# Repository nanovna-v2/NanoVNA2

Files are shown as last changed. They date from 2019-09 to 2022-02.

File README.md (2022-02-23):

# NanoVNA V2 (S-A-A-2)
This repository contains the NanoVNA V2 schematics and PCB layout designs.

Copyright (C) OwOTech 2020 <edelswartz123@gmail.com>, all rights reserved.

The design is licensed under CC-BY-NC-SA (see LICENSE file).

## V2_2 (V2.2) design files
- [v2_2.sch](v2_2.sch) (gEDA gschem schematic)
- [v2_2.pcb](v2_2.pcb) (gEDA PCB)
- [Schematic (png)](v2_2.png)
- [Schematic (pdf)](v2_2.pdf)

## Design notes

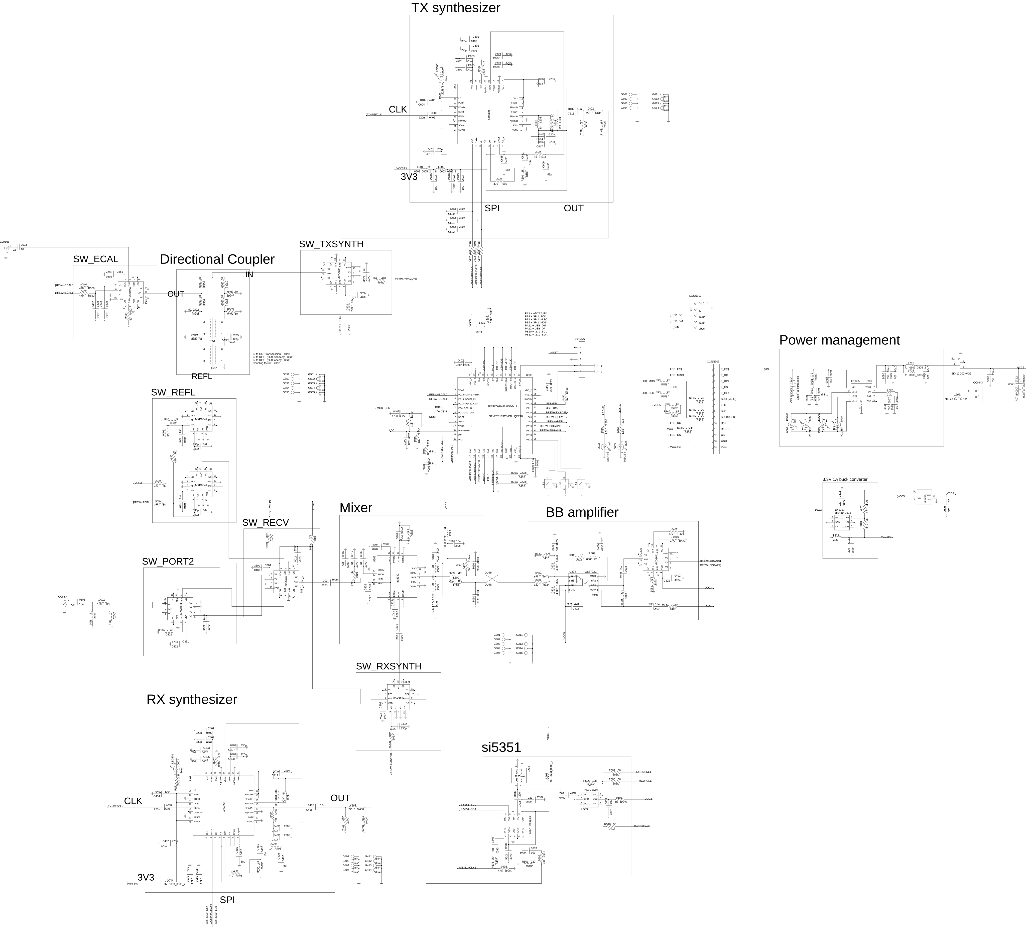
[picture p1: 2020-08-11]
v2_2.png

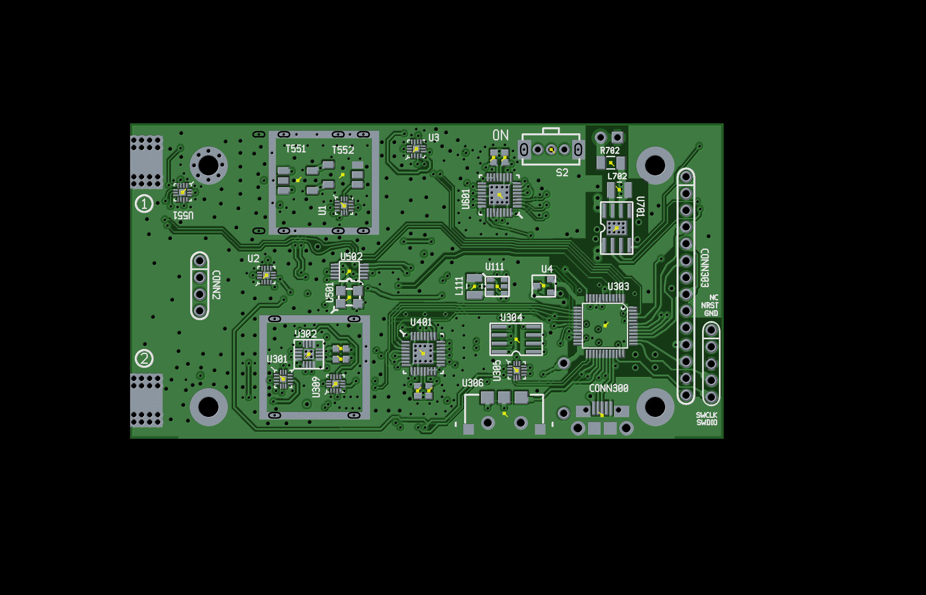
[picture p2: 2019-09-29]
fab/v2_0-20190929_12_02/v2_0-20190929_12_02-smt-top.png

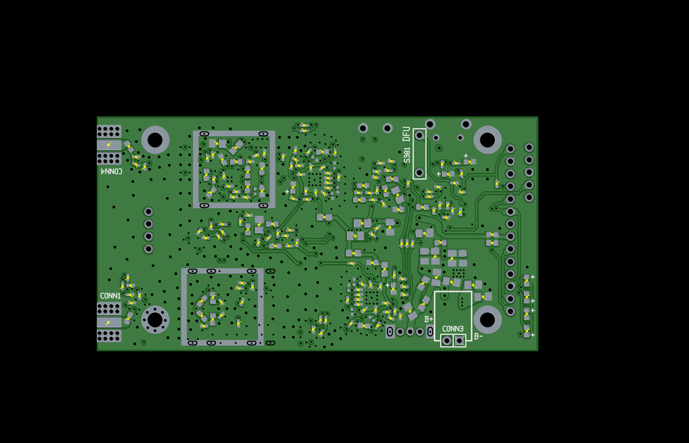
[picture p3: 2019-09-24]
fab/v2_0-20190924_08_28/v2_0-20190924_08_28-smt-bottom.png

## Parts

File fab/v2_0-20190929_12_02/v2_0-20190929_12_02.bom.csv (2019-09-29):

refdes | dni | device | footprint | value
G502 | unknown | terminal | shield_15.6_14.6 | unknown
R559 | unknown | RESISTOR | 0402 | 50
R558 | unknown | RESISTOR | 0402 | 50
R555 | unknown | RESISTOR | 0402 | 50
R553 | unknown | RESISTOR | 0402 | 50
R556 | unknown | RESISTOR | 0603 | 68
R554 | unknown | RESISTOR | 0603 | 68
R552 | unknown | RESISTOR | 0603 | 68
R551 | unknown | RESISTOR | 0603 | 68
R702 | unknown | PTC 2A | 1206 | unknown
R505 | unknown | RESISTOR | 0402 | 120
R504 | unknown | RESISTOR | 0402 | 50
R312 | unknown | RESISTOR | 0402 | 120
C9 | unknown | CAPACITOR | 0805 | 22u
R311 | unknown | RESISTOR | 0603 | 10
CONN5 | unknown | CONNECTOR_5 | connector5 | unknown
C710 | unknown | CAPACITOR | 0805 | 10u
S2 | unknown | SK-12D02-VG3 | SK-12D02-VG3 | unknown
R12 | unknown | RESISTOR | 0402 | 50
R609 | unknown | RESISTOR | 0402 | 470
R608 | unknown | RESISTOR | 0402 | 470
R607 | unknown | RESISTOR | 0402 | 470
C622 | unknown | CAPACITOR | 0402 | 330p
C621 | unknown | CAPACITOR | 0402 | 330p
C620 | unknown | CAPACITOR | 0402 | 330p
C616 | unknown | CAPACITOR | 0402 | 470n
C613 | unknown | CAPACITOR | 0603 | 10u
C8 | unknown | CAPACITOR | 0603 | 10u
CONN4 | unknown | BNC | custom_sma4 | unknown
R9 | unknown | RESISTOR | 0402 | 120
R11 | unknown | RESISTOR | 0402 | 75
R10 | unknown | RESISTOR | 0402 | 75
R563 | unknown | RESISTOR | 0402 | 50
C553 | unknown | CAPACITOR | 0402 | 330p
R562 | unknown | RESISTOR | 0402 | 470
C552 | unknown | CAPACITOR | 0402 | 330p
R560 | unknown | RESISTOR | 0402 | 470
C551 | unknown | CAPACITOR | 0402 | 470n
U551 | unknown | MXD8641 | mxd8641 | unknown
R503 | unknown | RESISTOR | 0603 | 2.2
C329 | unknown | CAPACITOR | 0402 | 470n
R310 | unknown | RESISTOR | 0402 | 2.2k
R309 | unknown | RESISTOR | 0402 | 2.2k
C416 | unknown | CAPACITOR | 0402 | 470n
C413 | unknown | CAPACITOR | 0603 | 10u
R308 | unknown | RESISTOR | 0402 | 470
C323 | unknown | CAPACITOR | 0402 | 330p
U306 | unknown | K1-1502SA-01 | K1-1502SA-01 | unknown
R307 | unknown | RESISTOR | 0402 | 2.2k
S301 | unknown | dipswitch-2 | dip2 | unknown
LED302 | unknown | LED | 0603 | red
R306 | unknown | RESISTOR | 0402 | 1.5k
R8 | unknown | RESISTOR | 0402 | 75
R7 | unknown | RESISTOR | 0402 | 220
U4 | unknown | xc6206-3.0 | SOT23 | unknown
L601 | unknown | INDUCTOR | 0603_0805_2 | fb
C619 | unknown | CAPACITOR | 0603 | 10u
L602 | unknown | INDUCTOR | 0603_0805_2 | fb
L401 | unknown | INDUCTOR | 0603_0805_2 | fb
C111 | unknown | CAPACITOR | 0805 | 22u
R111 | unknown | RESISTOR | 0402 | 2.2k
R112 | unknown | RESISTOR | 0402 | 10k
C112 | unknown | CAPACITOR | 0805 | 22u
L111 | unknown | INDUCTOR | 1008 | 2.2u
U111 | unknown | JW5211 | SOT26 | unknown
CONN3 | unknown | xh2.54-angled | CONNECTOR 1 2 | unknown
LED704 | unknown | LED | 0603 | red
LED703 | unknown | LED | 0603 | red
LED702 | unknown | LED | 0603 | red
LED701 | unknown | LED | 0603 | red
C709 | unknown | CAPACITOR | 0805 | 10u
L703 | unknown | INDUCTOR | 0603_0805_2 | fb
L701 | unknown | INDUCTOR | 0603_0805_2 | fb
C706 | unknown | CAPACITOR | 0805 | 10u
C705 | unknown | CAPACITOR | 0805 | 10u
R701 | unknown | RESISTOR | 0603 | 2.2
C703 | 1 | CAPACITOR | 0805 | 22u
C701 | unknown | CAPACITOR | 0805 | 22u
C704 | 1 | CAPACITOR | 0805 | 10u
C702 | unknown | CAPACITOR | 0805 | 10u
C708 | unknown | CAPACITOR | 0805 | 10u
C707 | unknown | CAPACITOR | 0805 | 10u
L702 | unknown | INDUCTOR | 1008 | 2.2u
U701 | unknown | IP5305 | SO8_EP | unknown
CONN2 | unknown | CONNECTOR_4 | connector4 | unknown
R305 | unknown | RESISTOR | 0402 | 470
R303 | unknown | RESISTOR | 0402 | 120
R304 | unknown | RESISTOR | 0402 | 1.5k
C321 | unknown | CAPACITOR | 0603 | 10u
C322 | unknown | CAPACITOR | 0402 | 470n
U305 | unknown | MXD8641 | mxd8641 | unknown
C618 | unknown | CAPACITOR | 0402 | 1n
R605 | unknown | RESISTOR | 0402 | 120
C609 | unknown | CAPACITOR | 0402 | 1n
R603 | unknown | RESISTOR | 0402 | 470
R604 | unknown | RESISTOR | 0402 | 470
C611 | unknown | CAPACITOR | 0402 | 470n
C615 | unknown | CAPACITOR | 0402 | 10n
C617 | unknown | CAPACITOR | 0402 | 220n
R606 | unknown | RESISTOR | 0402 | 50
C610 | unknown | CAPACITOR | 0402 | 470n
C604 | unknown | CAPACITOR | 0402 | 470n
C606 | unknown | CAPACITOR | 0402 | 220n
LED601 | unknown | LED | 0603 | blue
R601 | unknown | RESISTOR | 0402 | 2.2k
C614 | 1 | CAPACITOR | 0402 | 220n
C612 | unknown | CAPACITOR | 0402 | 220n
L604 | unknown | INDUCTOR | 0603 | rffb
L603 | unknown | INDUCTOR | 0603 | rffb
R602 | unknown | RESISTOR | 0402 | 4.7k
C605 | 1 | CAPACITOR | 0402 | 330p
C603 | unknown | CAPACITOR | 0402 | 220n
C602 | 1 | CAPACITOR | 0402 | 330p
C601 | unknown | CAPACITOR | 0402 | 220n
C607 | 1 | CAPACITOR | 0402 | 330p
C608 | unknown | CAPACITOR | 0402 | 220n
U601 | unknown | adf4350 | custom_qfn32 | unknown
R6 | unknown | RESISTOR | 0402 | 470
R5 | unknown | RESISTOR | 0402 | 220
C6 | unknown | CAPACITOR | 0402 | 330p
C7 | unknown | CAPACITOR | 0402 | 470n
U3 | unknown | MXD8641 | mxd8641 | unknown
G501 | unknown | terminal | shield_15.6_14.6 | unknown
R4 | unknown | RESISTOR | 0402 | 470
R3 | unknown | RESISTOR | 0402 | 220
C5 | unknown | CAPACITOR | 0402 | 330p
C4 | unknown | CAPACITOR | 0402 | 470n
U2 | unknown | MXD8641 | mxd8641 | unknown
R2 | unknown | RESISTOR | 0402 | 470
R1 | unknown | RESISTOR | 0402 | 220
C3 | unknown | CAPACITOR | 0402 | 330p
C2 | unknown | CAPACITOR | 0402 | 470n
R302 | unknown | RESISTOR | 0402 | 220
R301 | unknown | RESISTOR | 0402 | 470
C304 | unknown | CAPACITOR | 0402 | 330p
C305 | unknown | CAPACITOR | 0402 | 470n
L303 | unknown | INDUCTOR | 0603_0805_2 | fb
C303 | unknown | CAPACITOR | 0805 | 10u
U1 | unknown | MXD8641 | mxd8641 | unknown
U301 | unknown | MXD8641 | mxd8641 | unknown
C1 | unknown | CAPACITOR | 0603 | 10u
CONN1 | unknown | BNC | custom_sma4 | unknown
T552 | unknown | 617DB-1023=P3 | cx2156nl | unknown
R557 | unknown | RESISTOR | 0402 | 50
T551 | unknown | 617DB-1023=P3 | cx2156nl | unknown
G302 | unknown | terminal | shield_15.6_14.6 | unknown
G301 | unknown | terminal | shield_15.6_14.6 | unknown
C302 | unknown | CAPACITOR | 0402 | 470n
R501 | unknown | RESISTOR | 0402 | 220
R502 | unknown | RESISTOR | 0402 | 120
C505 | unknown | CAPACITOR | 0603 | 10u
C504 | unknown | CAPACITOR | 0402 | 470n
C418 | unknown | CAPACITOR | 0402 | 1n
C301 | unknown | CAPACITOR | 0603 | 10u
U309 | unknown | MXD8641 | mxd8641 | unknown
C502 | unknown | CAPACITOR | 0805 | 22u
C501 | unknown | CAPACITOR | 0402 | 220n
U501 | unknown | YSO680PR | tcxo3225 | unknown
C503 | unknown | CAPACITOR | 0603 | 10u
U502 | unknown | si5351a | MSOP10 | unknown
R405 | unknown | RESISTOR | 0402 | 120
C409 | unknown | CAPACITOR | 0402 | 1n
R403 | unknown | RESISTOR | 0402 | 470
R404 | unknown | RESISTOR | 0402 | 470
C411 | unknown | CAPACITOR | 0402 | 470n
C415 | unknown | CAPACITOR | 0402 | 10n
C417 | unknown | CAPACITOR | 0402 | 220n
R406 | unknown | RESISTOR | 0402 | 50
C410 | unknown | CAPACITOR | 0402 | 470n
C404 | unknown | CAPACITOR | 0402 | 470n
C406 | unknown | CAPACITOR | 0402 | 220n
LED401 | unknown | LED | 0603 | blue
R401 | unknown | RESISTOR | 0402 | 2.2k
C414 | 1 | CAPACITOR | 0402 | 220n
C412 | unknown | CAPACITOR | 0402 | 220n
L404 | unknown | INDUCTOR | 0603 | rffb
L403 | unknown | INDUCTOR | 0603 | rffb
R402 | unknown | RESISTOR | 0402 | 4.7k
C405 | 1 | CAPACITOR | 0402 | 330p
C403 | unknown | CAPACITOR | 0402 | 220n
C402 | 1 | CAPACITOR | 0402 | 330p
C401 | unknown | CAPACITOR | 0402 | 220n
C407 | 1 | CAPACITOR | 0402 | 330p
C408 | unknown | CAPACITOR | 0402 | 220n
U401 | unknown | adf4350 | custom_qfn32 | unknown
R340 | unknown | RESISTOR | 0603 | 68
R339 | unknown | RESISTOR | 0603 | 68
R341 | unknown | RESISTOR | 0402 | 10k
CONN303 | unknown | LCD-ILI9341-2.4in | connector14 | unknown
C337 | unknown | CAPACITOR | 0402 | 1n
R338 | unknown | RESISTOR | 0402 | 1.5k
LED301 | unknown | LED | 0603 | blue
R335 | unknown | RESISTOR | 0402 | 1.5k
CONN300 | unknown | CONNECTOR_5 | custom_microusb2 | unknown
C328 | unknown | CAPACITOR | 0402 | 470n
C327 | unknown | CAPACITOR | 0402 | 470n
C326 | unknown | CAPACITOR | 0402 | 470n
C324 | unknown | CAPACITOR | 0402 | 10n
R331 | unknown | RESISTOR | 0402 | 220
C325 | unknown | CAPACITOR | 0603 | 10u
R330 | unknown | RESISTOR | 0402 | 10k
R329 | unknown | RESISTOR | 0402 | 10k
C320 | unknown | CAPACITOR | 0402 | 470n
R323 | unknown | RESISTOR | 0402 | 4.7k
R322 | unknown | RESISTOR | 0402 | 4.7k
R321 | 1 | RESISTOR | 0402 | 50
C317 | unknown | CAPACITOR | 0603 | 10u
C315 | unknown | CAPACITOR | 0603 | 10u
R325 | unknown | RESISTOR | 0402 | 4.7k
R324 | unknown | RESISTOR | 0402 | 120
L302 | unknown | INDUCTOR | 0805 | 22u
C318 | unknown | CAPACITOR | 0603 | 220n
R328 | unknown | RESISTOR | 0402 | 2.2k
U304 | unknown | GS8052 | SO8 | unknown
C316 | unknown | CAPACITOR | 0603 | 220n
C312 | unknown | CAPACITOR | 0603 | 220n
L301 | unknown | INDUCTOR | 0603 | rffb
L300 | unknown | INDUCTOR | 0603 | rffb
C314 | unknown | CAPACITOR | 0402 | 470n
C311 | unknown | CAPACITOR | 0402 | 470n
R319 | unknown | RESISTOR | 0603 | 10
R317 | unknown | RESISTOR | 0603 | 10
C307 | unknown | CAPACITOR | 0603 | 10u
R314 | unknown | RESISTOR | 0402 | 75
C309 | unknown | CAPACITOR | 0402 | 470n
C310 | unknown | CAPACITOR | 0402 | 470n
C313 | unknown | CAPACITOR | 0603 | 10u
R315 | unknown | RESISTOR | 0402 | 2.2k
C308 | unknown | CAPACITOR | 0402 | 330p
U302 | unknown | ad8342 | QFN16_3_EP | unknown
C306 | unknown | CAPACITOR | 0603 | 10u
U303 | unknown | GD32F303CCT6 | LQFP48_7 | unknown

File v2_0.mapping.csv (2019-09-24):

device | footprint | value | expression | priority
CAPACITOR | * | * | (value+'F', device, footprint, '') | -1
RESISTOR | * | * | (value+'Ω 1%', device, footprint, '') | -1
INDUCTOR | * | * | (value+'H', device, footprint, '') | -1
* | * | * | (device,device,footprint,value) | -1
BGS14GA14 | * | * | 'BGS14GA14E6327XTSA1'
INDUCTOR | 0603_0805 | fb | ('GZ2012D601TF', device, '0805', '')
INDUCTOR | 0603_0805_2 | fb | ('GZ2012D601TF', device, '0805', '')
INDUCTOR | 0805_s | fb | ('GZ2012D601TF', device, '0805', '')
INDUCTOR | 0805 | fb | ('GZ2012D601TF', device, '0805', '')
INDUCTOR | 0603 | fb | ('FBMH1608HM601-T', device, footprint, '')
INDUCTOR | 0603 | rffb | ('FBMH1608HM601-T', device, footprint, '')
INDUCTOR | 0805 | 15n | 'CE201210-15NJ'
INDUCTOR | 0805 | 2.2u | 'CV201210-2R2K'
INDUCTOR | 0805 | 4.7u | 'CV201210-4R7K'
RESISTOR | * | 50 | ('49.9R 1%', device, footprint, '')
CAPACITOR | 0603_0805 | * | (value+'F', device, '0805', '')
CAPACITOR | 0402_l | * | (value+'F', device, '0402', '')
CAPACITOR | 0402_m | * | (value+'F', device, '0402', '')
CAPACITOR | 0402_2 | * | (value+'F', device, '0402', '')
CAPACITOR | 0805_s | * | (value+'F', device, '0805', '')
LED | 0603 | blue | ('blue', device, footprint, '')
LED | 0603 | green | ('green', device, footprint, '')
LED | 0603 | red | ('red', device, footprint, '')
LP0603A0947 | lp0603 | * | 'LP0603A0947ANTR'
LP0603A2140 | lp0603 | * | 'LP0603A2140ANTR'
LT1819 | SO8 | * | 'LT1819CS8#PBF'
USB3343 | QFN24_4_EP | * | 'USB3343-CP-TR'
W25Q32FV | custom_so8 | * | ('W25Q32JVSSIQ', 'W25Q32JV', 'SO8', value)
XC6SLX9 | LQFP144_20 | * | 'XC6SLX9-2TQG144C'
ad9200 | SSOP28 | * | 'AD9200JRSZ'
adf4350 | custom_qfn32 | * | ('ADF4350BCPZ', 'adf4350', 'QFN32_EP', value)
ap3419 | SOT26 | * | 'AP3429KTTR-G1'
cmy210 | custom_cmy211 | * | ('CMY210', 'cmy210', 'SOT23-6', value)
ad8342 | * | * | 'AD8342ACPZ'
nc7s04 | SC70_5 | * | 'NC7S04P5X'
pe4312 | QFN20_4_EP | * | 'PE4312MLBA-Z'
si53365 | TSSOP16 | * | 'SI53365-B-GT'
tcxo3225 | tcxo3225 | * | ('ASVTX-11-121-19.200MHZ-T', 'tcxo', '3225', value)
trf37a75 | trf37a75 | * | 'TRF37A75IDSGR'
ao3400 | * | * | ('AO3400A',device,'SOT-23-3L','')
dw01 | * | * | ('DW01+G',device,'SOT-23-6','')
xc6206 | * | * | ('XC6206P332MR',device,'SOT-23-3L','')
xc6206-3.0 | * | * | ('XC6206P302MR',device,'SOT-23-3L','')
NPN_TRANSISTOR | * | 2sc3356 | ('2SC3356-T1B-A',device,'SOT-23','')
INDUCTOR | mcw-0630 | 10uH | ('06030 (0630) 10uH 20% 4A', 'INDUCTOR', '06030', '10u')
CONNECTOR_5 | custom_microusb2 | * | ('szlcsc/C10418', 'CONNECTOR', 'micro usb', '')
* | custom_sma4 | * | ('CON-SMA-EDGE-S', 'CONNECTOR', 'SMA','')
CONNECTOR | * | * | 'DNI'
CONNECTOR_11 | * | * | 'DNI'
CONNECTOR_12 | * | * | 'DNI'
CONNECTOR_2 | * | * | 'DNI'
CONNECTOR1_2 | * | * | 'DNI'
CONNECTOR_4 | * | * | 'DNI'
CONNECTOR_5 | * | * | 'DNI'
CONNECTOR_3 | * | * | 'DNI'
CONNECTOR_9 | * | * | 'DNI'
CONNECTOR_14 | * | * | 'DNI'
edgepads | * | * | 'DNI'
CONNECTOR 1 2 | * | * | 'DNI'
connector9 | * | * | 'DNI'
sd_breakout | * | * | 'DNI'
HEADER3 | * | * | 'DNI'
terminal | * | * | 'DNI'
LCD-ILI9341-2.4in | * | * | 'LCD ILI9341 2.4in'
xh2.54-angled | * | * | 'XH-2.54 90 degrees'
dipswitch-2 | * | * | 'DSWB01LHGET'

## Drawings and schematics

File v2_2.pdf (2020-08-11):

# CLK

# SPI

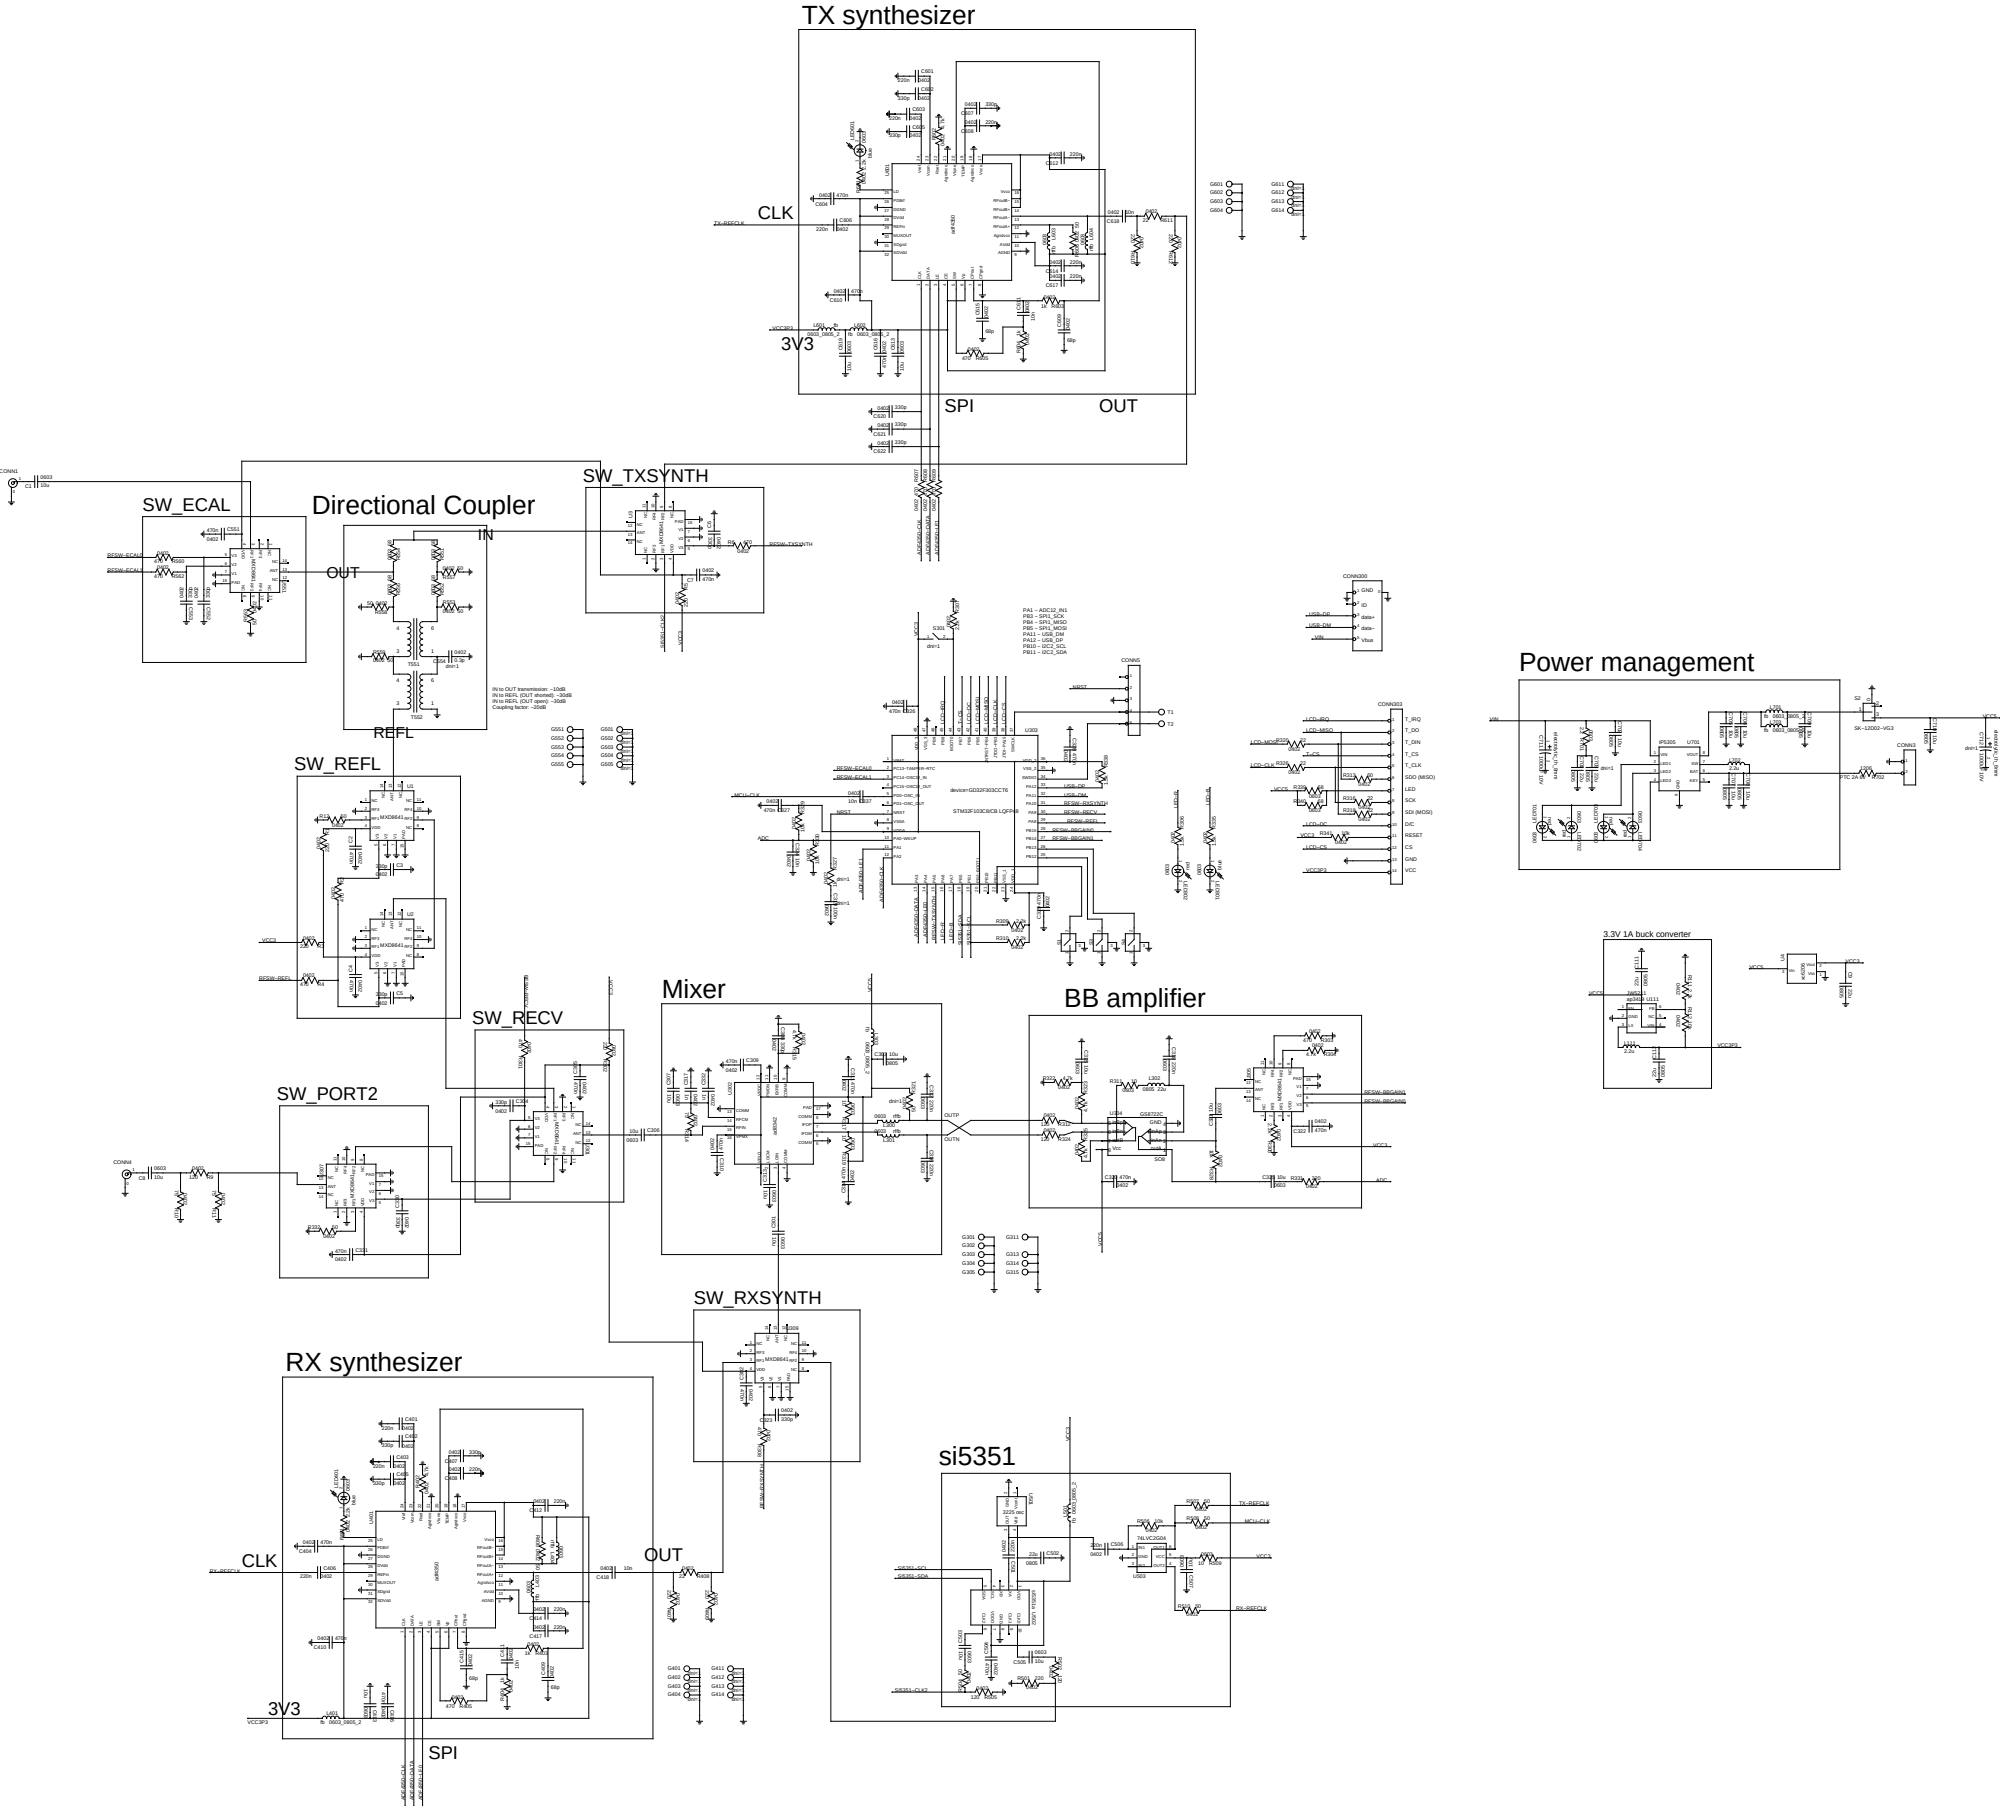
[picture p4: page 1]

IN to OUT transmission: −10dB
IN to REFL (OUT shorted): −30dB
IN to REFL (OUT open): −30dB
Coupling factor: −20dB

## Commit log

2019-09-04 pcb: wip
    [v2_0.sch]
2019-09-08 pcb: pending checklist
    [v2_0.sch]
2019-09-09 review 1
    [v2_0.sch]
2019-09-09 revise component values & bom optimization
    [v2_0.mapping.csv, v2_0.sch]
2019-09-10 label chip & led orientations
2019-09-10 add test_transitions.pcb
    [test_transitions.sch]
2019-09-10 redesign coupler to move baluns to the pcb top side
    [v2_0.sch]
2019-09-13 change micro usb footprint; move leds to bottom side
    [v2_0.sch]
2019-09-14 change ferrite bead footprint to 0603/0805 hybrid
    [v2_0.sch]
2019-09-14 update part numbers
    [v2_0.mapping.csv, v2_0.sch]
2019-09-24 add fabrication outputs
    [v2_0-20190924_08_28-jlc.fbom.csv, v2_0-20190924_08_28.bom.csv, v2_0-20190924_08_28.fbom.csv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]
2019-09-24 pcb: minor fixes
    [v2_0.mapping.csv, v2_0.sch]
2019-09-29 pcb: minor changes
    [v2_0.sch]
2019-10-05 v2_1 pcb wip
    [v2_1.sch]
2019-10-06 pcb: add termination resistors on lcd spi lines
    [v2_1.sch]
2019-11-16 v2lite pcb wip
    [v2lite_0.sch]
2019-11-21 v2_1 pcb finalized
    [v2_1.sch, v2lite_0.sch]
2019-12-18 copy v2_1 design files to v2_2
    [v2_2.sch]
2019-12-18 v2_2 pcb: nudge shield holes
2019-12-18 v2_2 pcb: remove copper in unplated slots
2019-12-18 v2_2 pcb: rotate T551 180 degrees
    [v2_2.sch]
2019-12-18 v2_2 pcb: tweak bridge layout
    [v2_2.sch]
2019-12-18 v2_2 pcb: change R555 to 0.3pF capacitor
    [v2_2.sch]
2019-12-18 v2_2 pcb: improve ad8342 decoupling
    [v2_2.sch]
2019-12-18 v2_2 pcb: tweak sma connector artwork
2019-12-19 v2_2 pcb: nudge shield clips to fit 17.5mm x 26mm shield can
2019-12-19 v2_2 pcb: change lcd connector supply to 3.3V rail; rework panel interconnections
    [v2_2.sch]
2019-12-19 v2_2 pcb: move one electrolytic to input side and change all electrolytics to horizontal orientation
    [v2_2.sch]
2019-12-19 v2_2 pcb: move some vias and other minor changes
2019-12-19 v2_2 pcb: move usb connector 1mm to the right (panel conflict)
2019-12-20 v2_2 pcb: add programming pads
    [v2_2.sch]
2019-12-20 v2_2 pcb: move one hole to accomodate all 4 holes of 2.8'' lcd
2019-12-20 v2_2 pcb: replace jog switch with 3 side mount pushbuttons
    [v2_2.sch]
2019-12-20 v2_2 pcb: add fiducials
2019-12-20 v2_2 pcb: adjust clearance of 5V trace
2019-12-20 v2_2 pcb: add board revision text
2019-12-22 v2_2 pcb: move power switch closer to edge; move led out of the way
2019-12-23 v2_2 pcb: fix mis-aligned ground plane cutout
2019-12-23 add v2lite_1
    [v2lite_1.sch]
2019-12-23 v2_2 pcb: mark unused shield can clips as DNI
    [v2_2.sch]
2019-12-23 v2_2 pcb: remove panelizing tabs
2019-12-23 v2_2 pcb: add a few ground vias
2019-12-25 v2_2 pcb: add led polarity indicators on silkscreen
2019-12-25 v2_2 pcb: mark one electrolytic as DNI
    [v2_2.sch]
2019-12-26 v2lite_1: adjust resistor value to one available from jlc smt
    [v2lite_1.sch]
